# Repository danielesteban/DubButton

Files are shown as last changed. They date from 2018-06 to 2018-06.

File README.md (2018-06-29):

# DubButton

Attiny + IR led == Dub at the push of a button

```
When we come home from work we need our dub fix.
Our smart TV is extremely slow and unresponsive.
The mobile interface is not any better.
Automation to the rescue!
```

It's basically a one button remote that:

- Powers up the TV
- Opens the youtube app
- Searches a random query based on a list of keywords
- Plays the first returned video

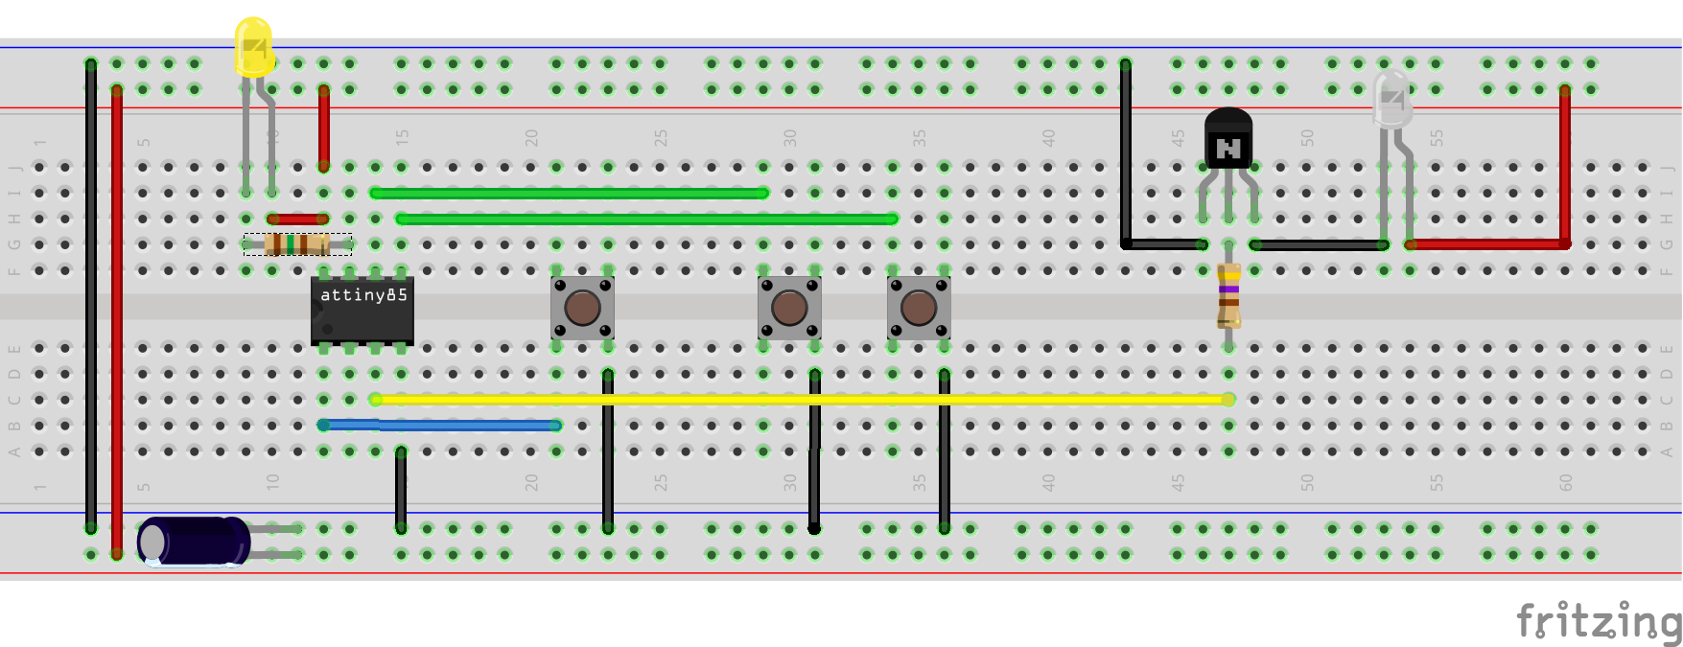
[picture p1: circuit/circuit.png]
Breadboard Circuit


```
The primary button (PB1) does the full sequence.
The secondary button (PB0) skips the power-up step (for when the TV is already on).
There's a third button that drops reset to ground in case we need to stop it mid-sequence.
The yellow led is just to have a visual feedback when it sends commands.
```

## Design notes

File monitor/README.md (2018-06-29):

```
This is a simple sketch to debug/monitor the IR output of the DubButton.
Upload it to any arduino board that has a hardware serial,
Connect an IR Receiver to it and open the serial monitor.
```

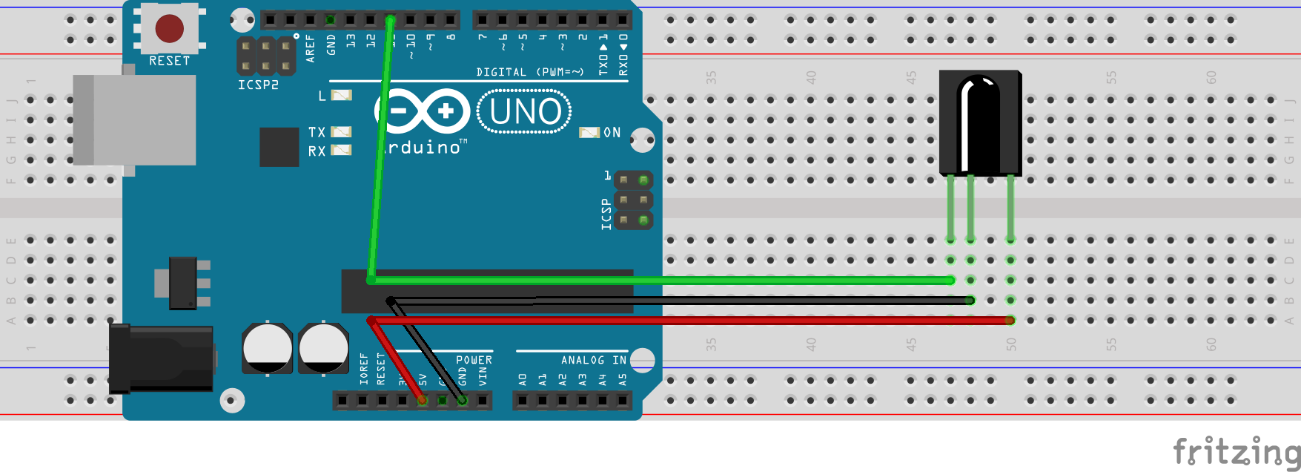
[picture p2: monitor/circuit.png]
Breadboard Circuit


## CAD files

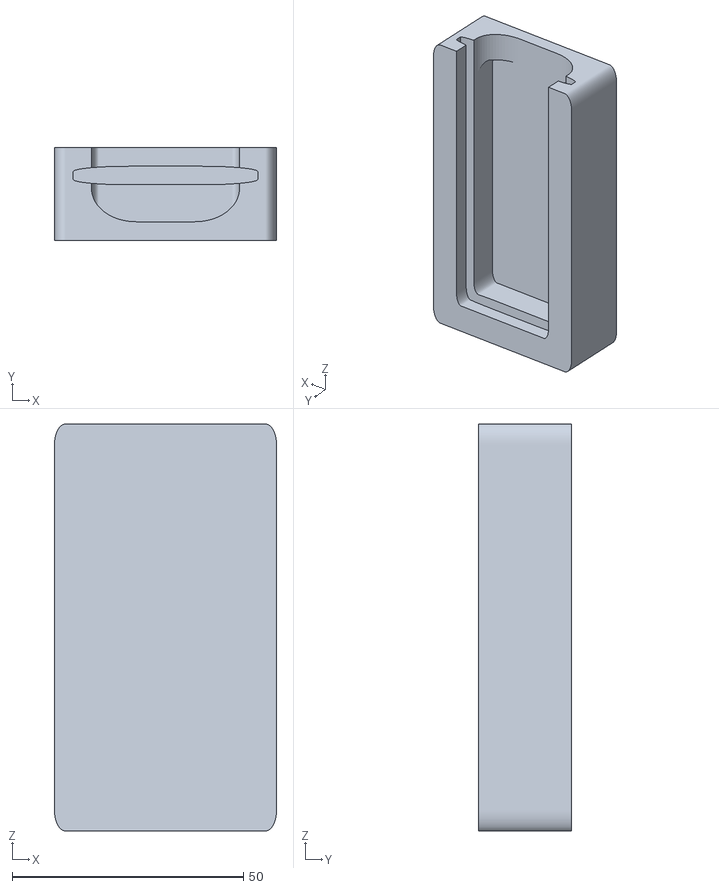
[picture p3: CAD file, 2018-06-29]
enclosure/enclosure.stl
48.0 x 20.0 x 88.0

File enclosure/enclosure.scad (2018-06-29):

WALL = 4;
WIDTH = 40 + (WALL * 2);
LENGTH = 80 + (WALL * 2);

module Box(width, length, height, corner = 0.1) {
  scale([width, length, height]) {
    minkowski() {
      cube([1 - corner, 1 - corner, 0.5], center = true);
      cylinder($fn=64, d=corner, h=0.5, center = true);
    }
  }
}

color("Blue") {
  rotate([90, 0, 0]) {
    difference() {
      translate([0, 0, WALL * 2.5]) {
        Box(WIDTH, LENGTH, WALL * 5);
      }
      translate([0, 0, WALL * 1.5]) {
        Box(WIDTH - WALL * 4, LENGTH - WALL * 4, WALL * 5);
      }
      translate([0, (LENGTH * 0.5) - WALL, WALL]) {
        rotate([90, 0, 0]) {
          Box(WIDTH - (WALL * 4.0), WALL * 6, WALL * 4, 0.6);
        }
      }
      translate([0, WALL, WALL * 1.5]) {
        rotate([90, 0, 0]) {
          Box(WIDTH - WALL * 2, WALL, LENGTH, 0.6);
        }
      }
    }
  }
}

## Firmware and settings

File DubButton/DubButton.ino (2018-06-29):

#include <Arduino.h>
#include "ir.h"

// I/O config
#define PRIMARY_BUTTON_PIN 1
#define SECONDARY_BUTTON_PIN 0
#define FEEDBACK_LED_PIN 2

// Youtube app keyboard config
#define KEYBOARD_STRIDE 7
#define KEYBOARD_HEIGHT 4
#define KEYBOARD_SPANISH 1 // Set this flag if your youtube app keyboard has an "Ñ"

struct {
  uint8_t pin;
  uint8_t read;
  uint8_t state;
  uint32_t debounce;
} buttons[2] = {{ PRIMARY_BUTTON_PIN, HIGH, HIGH, 0 }, { SECONDARY_BUTTON_PIN, HIGH, HIGH, 0 }};

extern const char* const keywords[] PROGMEM;
extern const uint8_t num_keywords;

void setup() {
  // Setup buttons
  for (int i = 0; i < 2; i++) {
    pinMode(buttons[i].pin, INPUT_PULLUP);
  }
  // Setup feedback led
  pinMode(FEEDBACK_LED_PIN, OUTPUT);
  digitalWrite(FEEDBACK_LED_PIN, HIGH);
  // Seed the RNG
  randomSeed(analogRead(A3));
  // Enable IR output
  IR::enableIROut();
}

// Samsung TV IR codes
#define POWER 0xE0E040BF
#define MUTE 0xE0E0F00F
#define SMART_HUB 0xE0E09E61
#define UP 0xE0E006F9
#define LEFT 0xE0E0A659
#define RIGHT 0xE0E046B9
#define DOWN 0xE0E08679
#define ENTER 0xE0E016E9

void send(const uint32_t code, const uint32_t wait) {
  // Pulse feedback led & send IR code
  digitalWrite(FEEDBACK_LED_PIN, LOW);
  IR::sendSamsung(code);
  digitalWrite(FEEDBACK_LED_PIN, HIGH);
  delay(wait);
}

void navigateGrid(const uint8_t col, const uint8_t row, uint8_t& currentCol, uint8_t& currentRow) {
  // Navigate through the keyboard grid
  {
    const int8_t distance = (int8_t) row - currentRow;
    if (distance != 0) {
      const uint32_t direction = distance > 0 ? DOWN : UP;
      for (uint8_t y = 0; y < abs(distance); y++) send(direction, 500);
      currentRow = row;
    }
  }
  {
    const int8_t distance = (int8_t) col - currentCol;
    if (distance != 0) {
      const uint32_t direction = distance > 0 ? RIGHT : LEFT;
      for (uint8_t x = 0; x < abs(distance); x++) send(direction, 500);
      currentCol = col;
    }
  }
}

void openYoutube() {
  // Smart hub
  send(SMART_HUB, 10000);
  // Recent -> Featured
  send(LEFT, 5000);
  send(ENTER, 5000);
  // Apps menu
  send(ENTER, 10000);
  // Go thrice to the right
  // You'll may need to modify this to match the
  // youtube app grid position on your TV
  send(RIGHT, 1000);
  send(RIGHT, 1000);
  send(RIGHT, 1000);
  // Start youtube app
  send(ENTER, 30000);
}

void playSomeMusic() {
  // Navigate to search
  send(LEFT, 1000);
  send(LEFT, 1000);
  send(UP, 3000);
  // Navigate to keyboard
  send(RIGHT, 500);
  send(RIGHT, 500);
  // Initialize query
  uint8_t query[num_keywords];
  for (uint8_t i = 0; i < num_keywords; i++) query[i] = i;
  // Shuffle query
  for (uint8_t j = 0; j < num_keywords; j++) {
    for (uint8_t i = 0; i < num_keywords; i++) {
      uint8_t n = random(0, num_keywords);
      uint8_t temp = query[n];
      query[n] = query[i];
      query[i] = temp;
    }
  }
  // Type search query
  uint8_t col = 0;
  uint8_t row = 0;
  const uint8_t numWords = min(3, num_keywords);
  for (uint8_t i = 0; i < numWords; i++) {
    // Fetch keyword
    const char* keyword = pgm_read_word(&(keywords[query[i]]));
    for (uint8_t l = 0; l < strlen_P(keyword); l++) {
      uint8_t letter = toupper(pgm_read_byte_near(keyword + l)) - 'A';
      #ifdef KEYBOARD_SPANISH
      // Skip "Ñ"
      if (letter > 13) letter++;
      #endif
      // Navigate to letter
      navigateGrid(letter % KEYBOARD_STRIDE, letter / KEYBOARD_STRIDE, col, row);
      // Submit letter
      send(ENTER, 500);
    }
    // Navigate to spacebar
    navigateGrid(col, KEYBOARD_HEIGHT, col, row);
    if (i < numWords - 1) {
      // Submit spacebar
      send(ENTER, 500);
    }
  }
  // Navigate to search button
  send(RIGHT, 500);
  // Submit search
  send(ENTER, 3000);
  // Play video
  send(ENTER, 0);
}

void onButton(const uint8_t button) {
  switch (button) {
    case 0:
      // Primary button
      // Power up the TV
      send(POWER, 15000);
      // Keep it quiet while it loads up
      send(MUTE, 60000);
      // Preload smart hub
      send(SMART_HUB, 15000);
      send(LEFT, 5000);
      send(ENTER, 40000);
      // TV should be ready
      openYoutube();
      // Give it some extra time to load youtube for the first time
      send(MUTE, 10000);
      break;
    case 1:
      // Secondary button
      // TV is already powered & ready
      openYoutube();
      break;
  }
  playSomeMusic();
}

void loop() {
  const uint32_t now = millis();
  for (uint8_t i = 0; i < 2; i++) {
    // Update button state
    const uint8_t state = digitalRead(buttons[i].pin);
    if (buttons[i].read != state) {
      buttons[i].debounce = now;
    }
    buttons[i].read = state;
    if (buttons[i].state != state && (now - buttons[i].debounce) > 10) {
      buttons[i].state = state;
      if (state == LOW) {
        onButton(i);
      }
    }
  }
}

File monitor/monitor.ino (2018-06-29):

// This is a simple sketch to debug/monitor the IR output of the DubButton.
// Upload it to any arduino board that has a hardware serial,
// Connect an IR Receiver to it and open the serial monitor.

#include <IRremote.h>

#define RECEIVER_PIN 11
IRrecv irrecv(RECEIVER_PIN);

// Samsung TV IR codes
#define POWER 0xE0E040BF
#define MUTE 0xE0E0F00F
#define SMART_HUB 0xE0E09E61
#define UP 0xE0E006F9
#define LEFT 0xE0E0A659
#define RIGHT 0xE0E046B9
#define DOWN 0xE0E08679
#define ENTER 0xE0E016E9

void setup() {
  // Start receiving codes
  Serial.begin(115200);
  irrecv.enableIRIn();
}

void loop() {
  decode_results results;
  if (irrecv.decode(&results)) {
    if (results.decode_type == SAMSUNG) {
      // Dump the code
      switch (results.value) {
        case POWER:
          Serial.println("POWER");
          break;
        case MUTE:
          Serial.println("MUTE");
          break;
        case SMART_HUB:
          Serial.println("SMART_HUB");
          break;
        case UP:
          Serial.println("UP");
          break;
        case LEFT:
          Serial.println("LEFT");
          break;
        case RIGHT:
          Serial.println("RIGHT");
          break;
        case DOWN:
          Serial.println("DOWN");
          break;
        case ENTER:
          Serial.println("ENTER");
          break;
        default:
          Serial.println("UNKNOWN");
          break;
      }
    }
    irrecv.resume();
  }
}

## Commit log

2018-06-29 Forgot a case when refactoring the monitor into the repo
2018-06-29 Button logic refactor
2018-06-29 Adjust timings + swap keyboard navigation so it works properly in the spacebar case
    [DubButton.ino]
